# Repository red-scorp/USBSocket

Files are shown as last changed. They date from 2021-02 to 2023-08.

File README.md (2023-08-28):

# USBSocket project

USB Socket board came into existence as alternative to cheap miniUSB adapters which we not good enough for me.
These cheap boards do not care about D+/D- traced being equally long which is essential for USB wiring.
I had to design my own microUSB adapter board to fit my needs.

Following types of boards are available:

- **Type1** is breadboard friendly **microUSB** socket
- **Type2** is cable mount friendly **microUSB** socket
- **Type3** is breadboard friendly **miniUSB** socket
- **Type4** is cable mount friendly **miniUSB** socket
- **Type5** is breadboard friendly **USB** socket
- **Type6** is cable mount friendly **USB** socket
- **Type7** is breadboard friendly **PCB-USB** socket
- **Type8** is cable mount friendly **PCB-USB** socket
- **Type9** is breadboard friendly **USB Type-C** socket
- **Type10** is cable mount friendly **USB Type-C** socket

## USBSocket_Type1_v1.0

**USBSocket_Type1_v1.0** is a simple microUSB adapter board, which mostly designed to be breadboard friendly.

Preview:

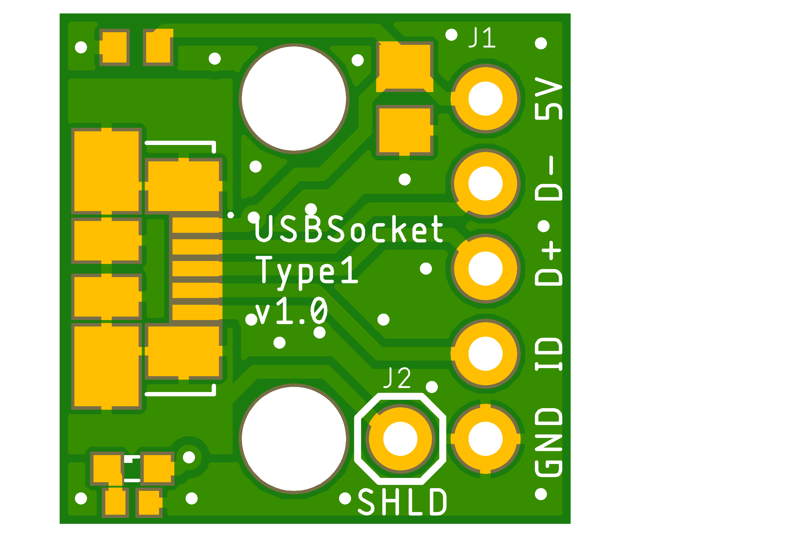
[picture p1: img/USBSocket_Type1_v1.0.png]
USBSocket_Type1_v1.0 preview


[Schematics in PDF format](doc/USBSocket_Type1_v1.0.pdf)

Features:

- 2.54mm (0.1") raster breadboard friendly
- small size
- includes decoupling capacitor
- includes power LED indicator
- 3mm mount holes

CAM files are available.

## USBSocket_Type2_v1.0

**USBSocket_Type2_v1.0** is a simple microUSB adapter board mostly usable for smaller or cable applications.

Preview:

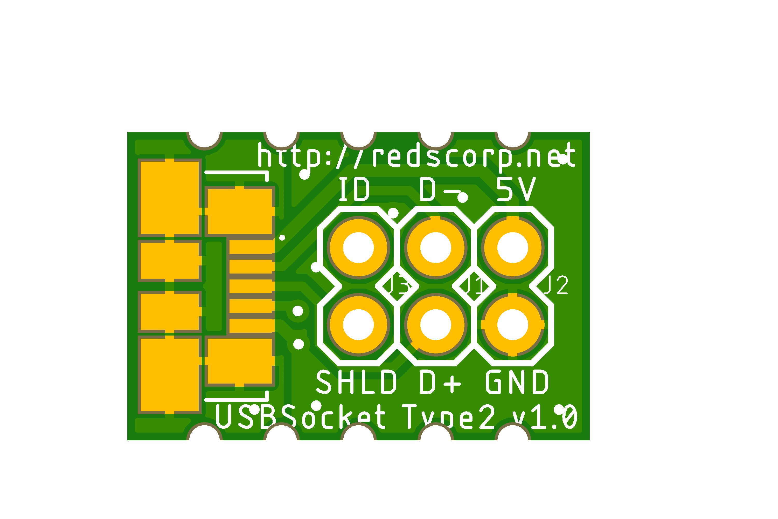
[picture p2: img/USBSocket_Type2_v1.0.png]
USBSocket_Type2_v1.0 preview


[Schematics in PDF format](doc/USBSocket_Type2_v1.0.pdf)

Features:

- 2.54mm (0.1") raster board friendly
- even smaller size
- suitable for cable mount
- shrink-tube friendly

CAM files are available.

## USBSocket_Type3_v1.0

**USBSocket_Type3_v1.0** is a simple miniUSB adapter board, which mostly designed to be breadboard friendly.

Preview:

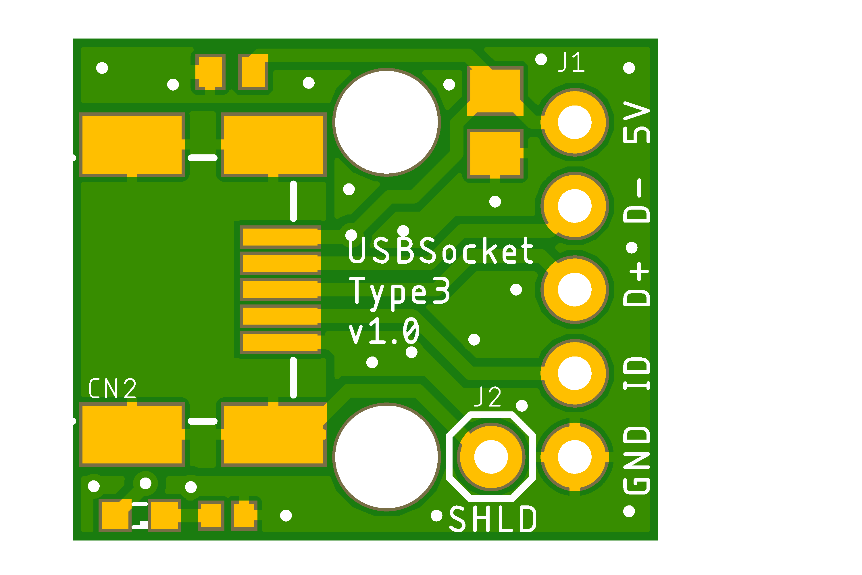
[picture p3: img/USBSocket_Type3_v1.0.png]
USBSocket_Type3_v1.0 preview


[Schematics in PDF format](doc/USBSocket_Type3_v1.0.pdf)

Features:

- 2.54mm (0.1") raster breadboard friendly
- small size
- includes decoupling capacitor
- includes power LED indicator
- 3mm mount holes

CAM files are available.

## USBSocket_Type4_v1.0

**USBSocket_Type4_v1.0** is a simple miniUSB adapter board mostly usable for smaller or cable applications.

Preview:

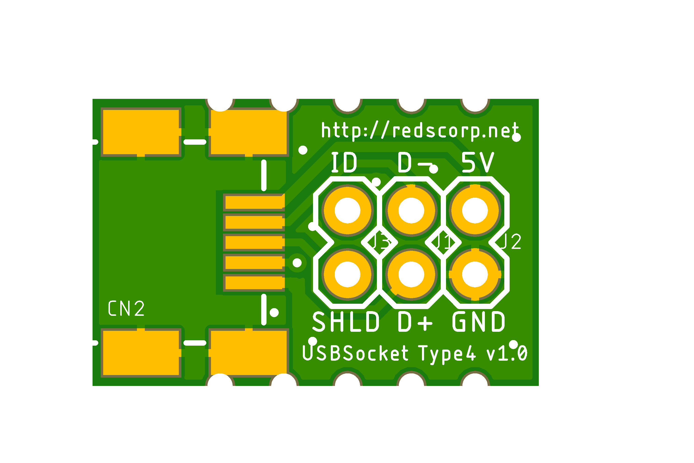
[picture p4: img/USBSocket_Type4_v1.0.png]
USBSocket_Type4_v1.0 preview


[Schematics in PDF format](doc/USBSocket_Type4_v1.0.pdf)

Features:

- 2.54mm (0.1") raster board friendly
- even smaller size
- suitable for cable mount
- shrink-tube friendly

CAM files are available.

## USBSocket_Type5_v1.0

**USBSocket_Type5_v1.0** is a simple USB adapter board, which mostly designed to be breadboard friendly.

Preview:

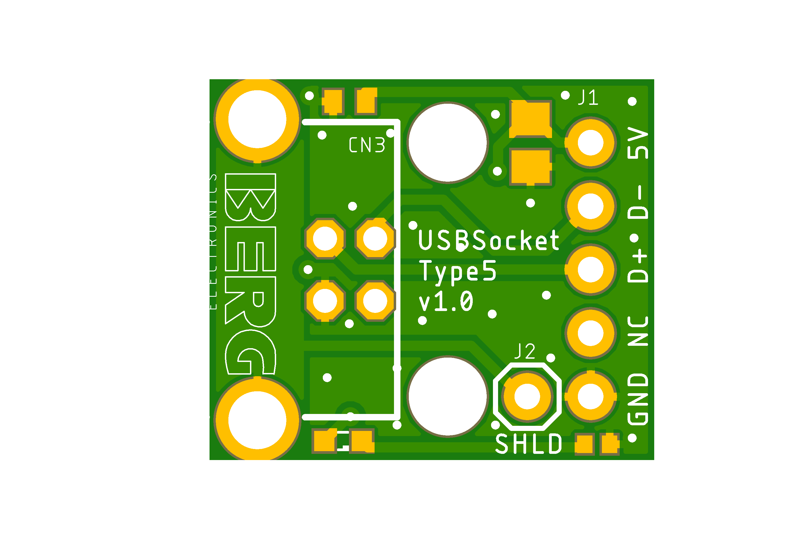
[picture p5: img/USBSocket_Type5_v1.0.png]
USBSocket_Type5_v1.0 preview


[Schematics in PDF format](doc/USBSocket_Type5_v1.0.pdf)

Features:

- 2.54mm (0.1") raster breadboard friendly
- small size
- includes decoupling capacitor
- includes power LED indicator
- 3mm mount holes

CAM files are available.

## USBSocket_Type6_v1.0

**USBSocket_Type6_v1.0** is a simple USB adapter board mostly usable for smaller or cable applications.

Preview:

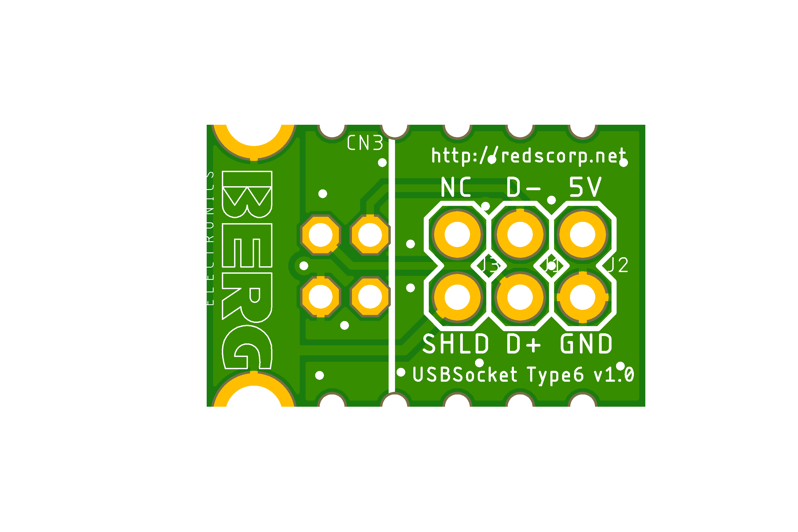
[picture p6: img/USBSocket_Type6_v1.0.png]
USBSocket_Type6_v1.0 preview


[Schematics in PDF format](doc/USBSocket_Type6_v1.0.pdf)

Features:

- 2.54mm (0.1") raster board friendly
- even smaller size
- suitable for cable mount
- shrink-tube friendly

CAM files are available.

## USBSocket_Type7_v1.0

**USBSocket_Type7_v1.0** is a simple PCB-USB adapter board, which mostly designed to be breadboard friendly.
This PCB board should be about 1.6-2.0mm thick!

Preview:

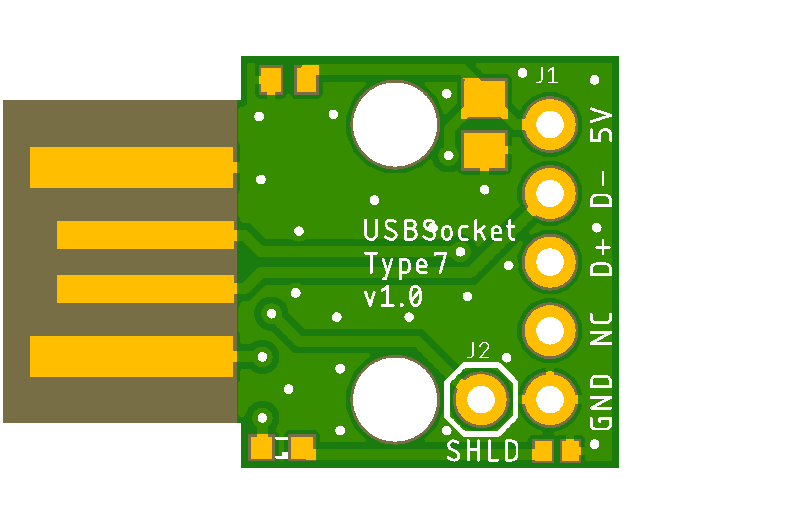
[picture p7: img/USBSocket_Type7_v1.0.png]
USBSocket_Type7_v1.0 preview


[Schematics in PDF format](doc/USBSocket_Type7_v1.0.pdf)

Features:

- 2.54mm (0.1") raster breadboard friendly
- small size
- includes decoupling capacitor
- includes power LED indicator
- 3mm mount holes

CAM files are available.

## USBSocket_Type8_v1.0

**USBSocket_Type8_v1.0** is a simple PCB-USB adapter board mostly usable for smaller or cable applications.
This PCB board should be about 1.6-2.0mm thick!

Preview:

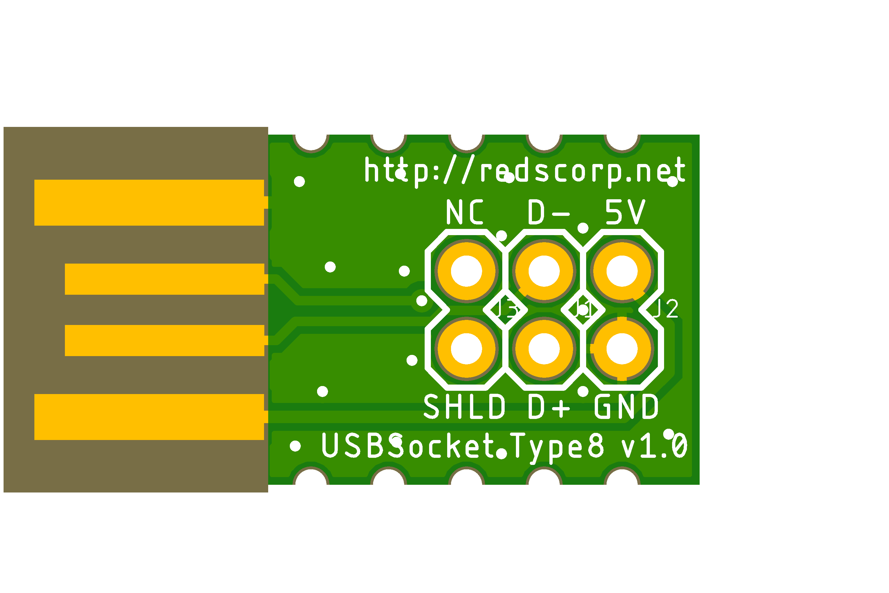
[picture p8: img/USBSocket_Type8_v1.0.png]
USBSocket_Type8_v1.0 preview


[Schematics in PDF format](doc/USBSocket_Type8_v1.0.pdf)

Features:

- 2.54mm (0.1") raster board friendly
- even smaller size
- suitable for cable mount
- shrink-tube friendly

CAM files are available.

## USBSocket_Type9_v1.0

**USBSocket_Type9_v1.0** is a simple USB Type-C adapter board, which mostly designed to be breadboard friendly.

Preview:

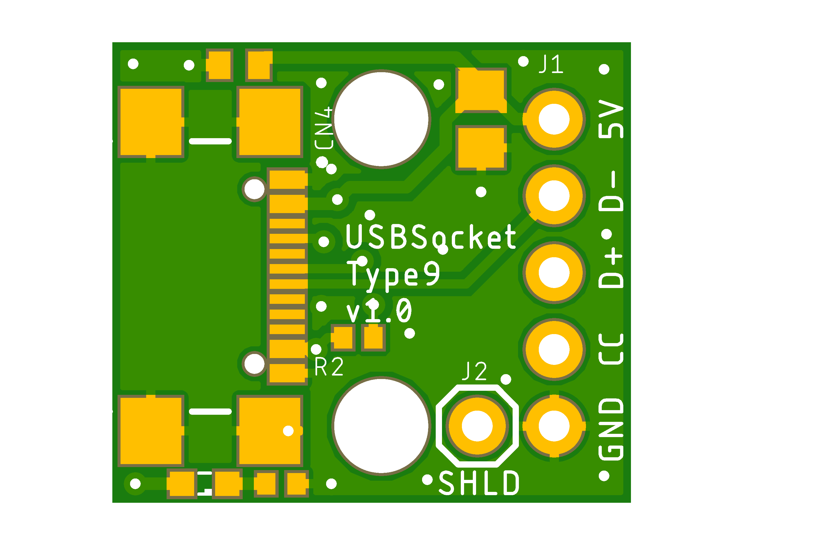
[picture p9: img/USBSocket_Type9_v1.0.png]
USBSocket_Type9_v1.0 preview


[Schematics in PDF format](doc/USBSocket_Type9_v1.0.pdf)

Features:

- 2.54mm (0.1") raster breadboard friendly
- small size
- includes decoupling capacitor
- includes power LED indicator
- 3mm mount holes

CAM files are available.

## USBSocket_Type10_v1.0

**USBSocket_Type10_v1.0** is a simple USB Type-C adapter board mostly usable for smaller or cable applications.

Preview:

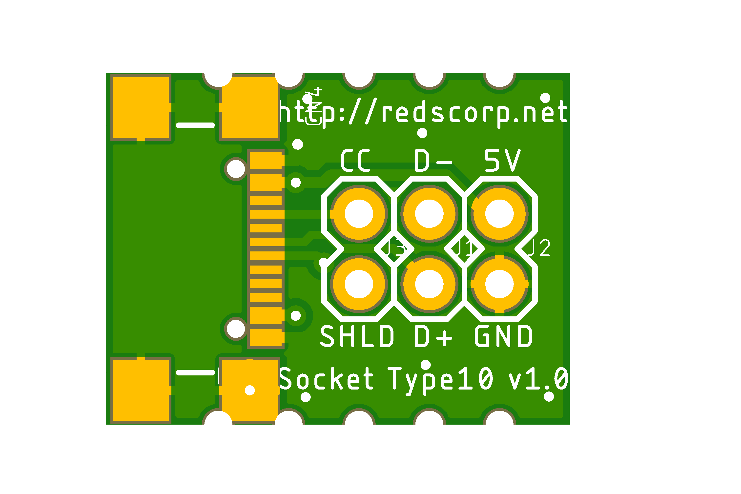
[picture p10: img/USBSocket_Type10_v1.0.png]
USBSocket_Type10_v1.0 preview


[Schematics in PDF format](doc/USBSocket_Type10_v1.0.pdf)

Features:

- 2.54mm (0.1") raster board friendly
- even smaller size
- suitable for cable mount
- shrink-tube friendly

CAM files are available.

## BOM

Bill Of Materials is currently available only for LCSC Electronic Components Distributor, which is probably cheapest anyway.

### LCSC BOM

|Designator  |Part/Value |Package/Footprint |LCSC # |
|---|---|---|---|
|CN1 |MOLEX 473460001 |SMD |C132560  |
|CN2 |MOLEX 675031230 |SMD |C136452  |
|CN3 |MOLEX 670688000 |TH |C114097  |
|CN4 |Hanbo Electronic MC-107S |SMD |C2874570 |
|C1\* |Cap. 47uF |0805 |C109461  |
|C2\* |Cap. 100nF |0402 |C60474 |
|LED1\* |LED Green |0603 |C364559  |
|R1\* |Res. 1K |0402 |C384390  |
|R2\* |Res. 56K |0402 |C25796 |

\*) These passive components are optional but it's recommended to install them.

## How to help

Your contributions as code, resources, or finances are welcome! Please contact me directly via email at andriy.golovnya@gmail.com or through my [GitHub profile](https://github.com/red-scorp).

If you'd like to make a financial contribution, you can donate via [PayPal](http://paypal.me/redscorp) or [Ko-Fi](http://ko-fi.com/redscorp). Your support is greatly appreciated.

Thanks in advance!

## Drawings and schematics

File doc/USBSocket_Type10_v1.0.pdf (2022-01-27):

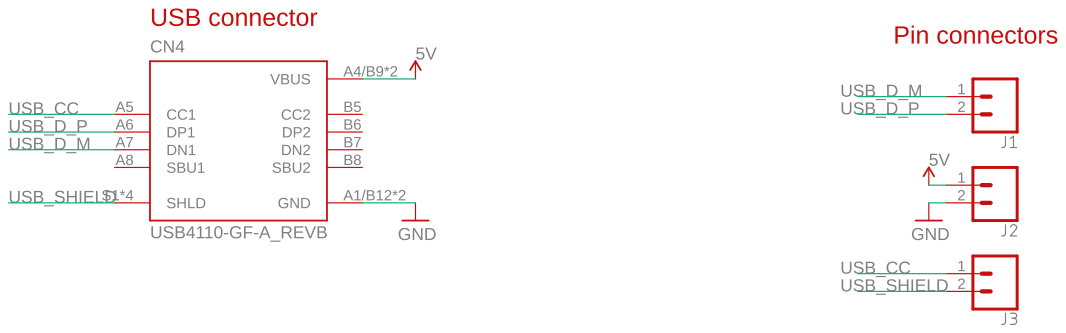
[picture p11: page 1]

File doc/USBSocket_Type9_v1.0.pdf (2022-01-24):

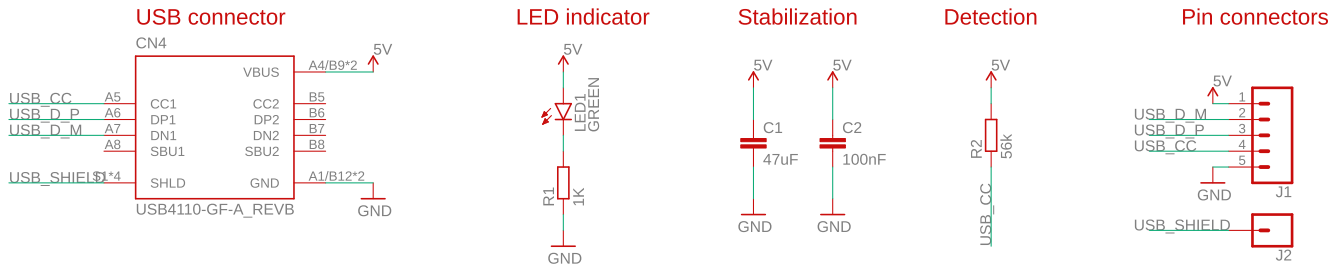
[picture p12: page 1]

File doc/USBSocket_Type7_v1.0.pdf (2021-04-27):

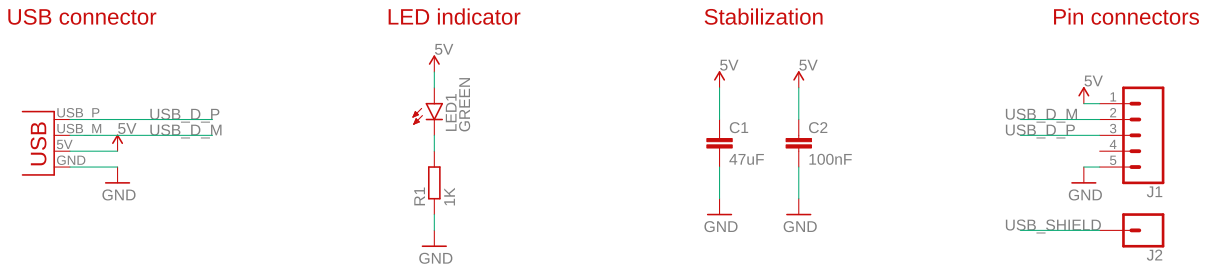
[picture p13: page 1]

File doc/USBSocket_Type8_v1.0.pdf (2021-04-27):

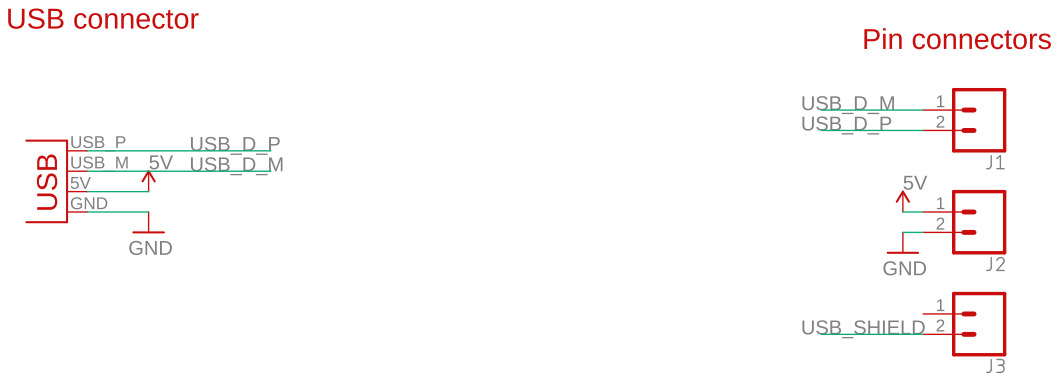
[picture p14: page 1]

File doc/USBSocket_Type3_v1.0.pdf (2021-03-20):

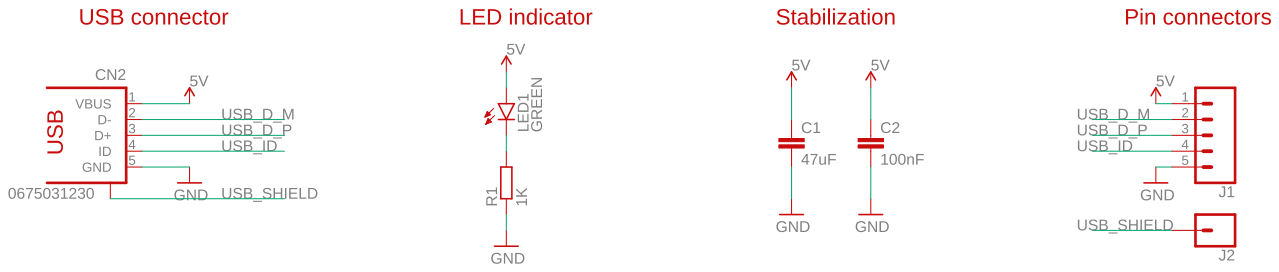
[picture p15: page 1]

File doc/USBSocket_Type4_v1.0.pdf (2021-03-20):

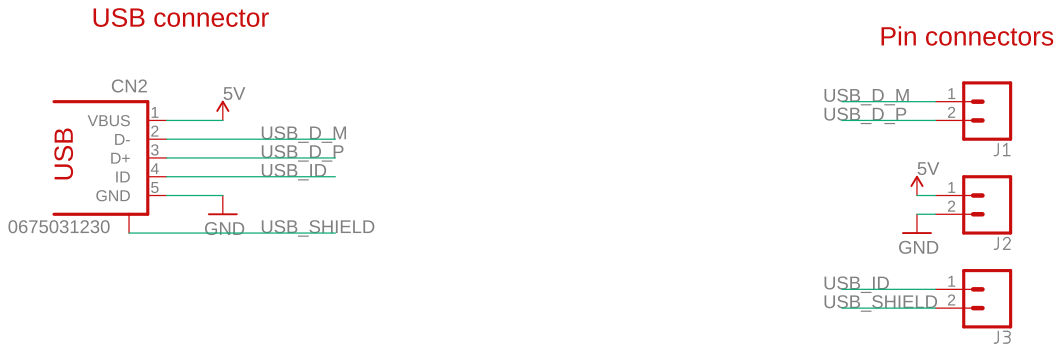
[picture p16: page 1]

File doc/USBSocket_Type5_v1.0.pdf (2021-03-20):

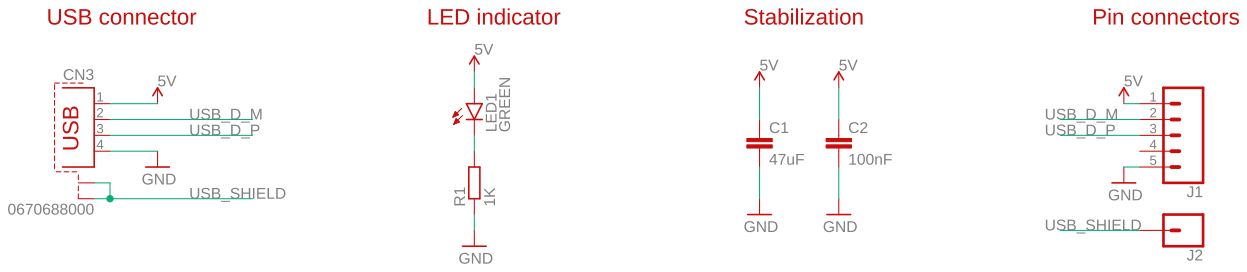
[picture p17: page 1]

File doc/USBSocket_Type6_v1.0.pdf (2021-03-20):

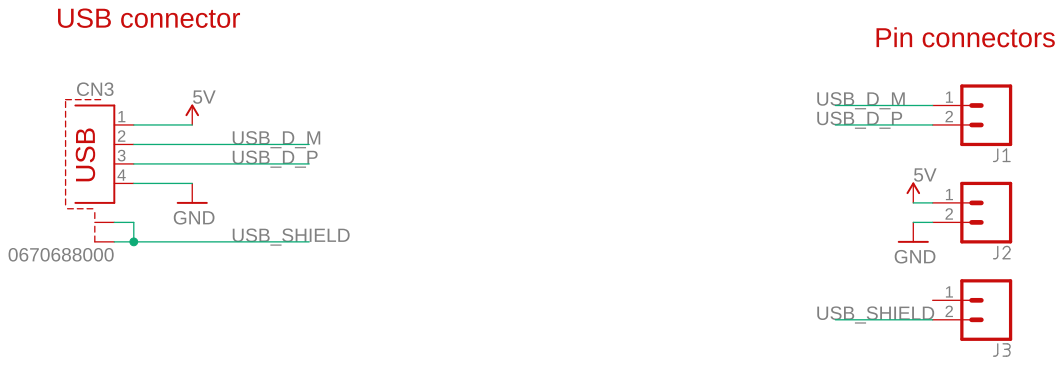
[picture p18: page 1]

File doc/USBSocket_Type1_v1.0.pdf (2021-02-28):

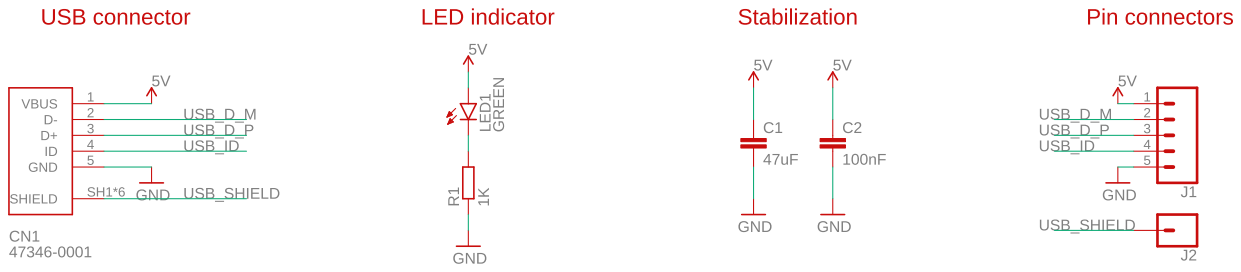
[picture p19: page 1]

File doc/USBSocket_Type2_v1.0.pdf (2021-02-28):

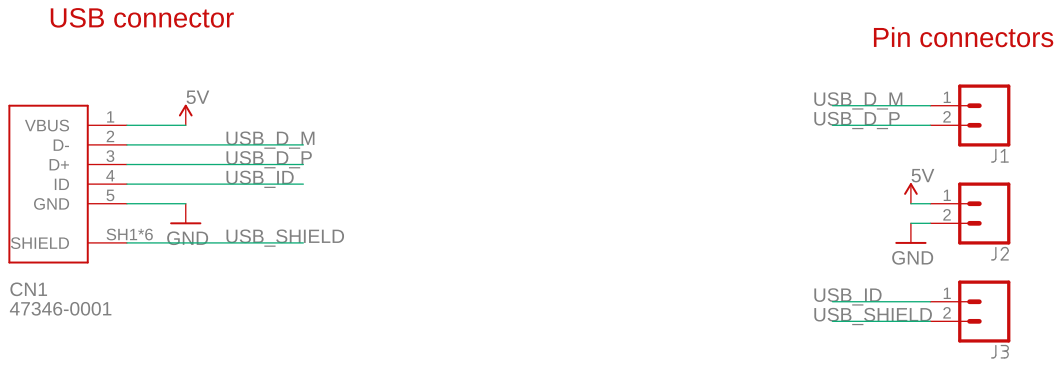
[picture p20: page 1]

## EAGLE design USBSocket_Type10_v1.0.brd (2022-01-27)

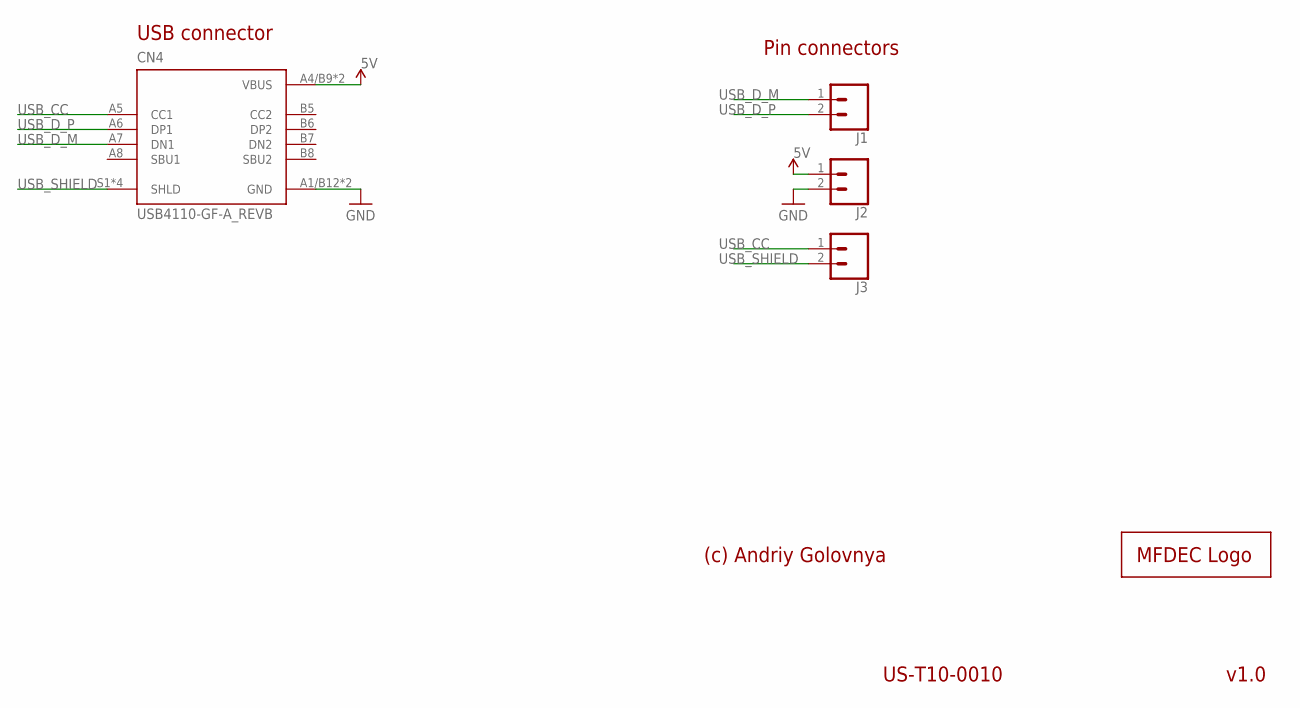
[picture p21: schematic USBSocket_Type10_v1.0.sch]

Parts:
CN4: USB4110-GF-A_REVB; GCT_USB4110-GF-A_REVB
J1, J2, J3: CONN_02; 1X02
LOGO1: MFDECLOGO_L_10MM; MFDEC_L_10MM

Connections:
5V: CN4.A4/B9 (VBUS), CN4.B4/A9 (VBUS), J2.1
GND: CN4.A1/B12 (GND), CN4.B1/A12 (GND), J2.2
USB_CC: CN4.A5 (CC1), J3.1
USB_D_M: CN4.A7 (DN1), J1.1
USB_D_P: CN4.A6 (DP1), J1.2
USB_SHIELD: CN4.S1 (SHLD), CN4.S2 (SHLD), CN4.S3 (SHLD), CN4.S4 (SHLD), J3.2

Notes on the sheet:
USB connector
v1.0
(c) Andriy Golovnya
US-T10-0010
Pin connectors

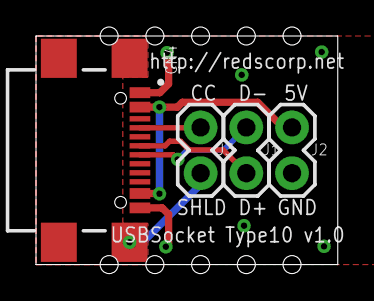
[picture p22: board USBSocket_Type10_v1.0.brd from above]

Board: 2 copper layers, 16.8 x 12.7 mm, 5 parts (1 on the bottom side), 6 nets.

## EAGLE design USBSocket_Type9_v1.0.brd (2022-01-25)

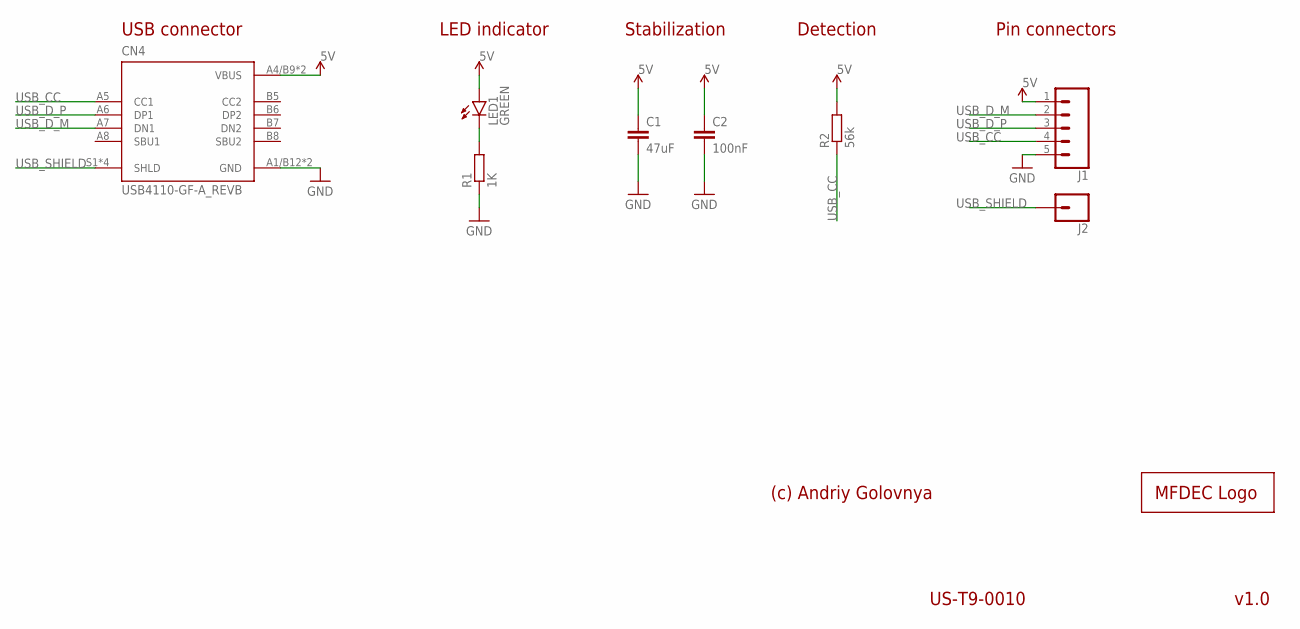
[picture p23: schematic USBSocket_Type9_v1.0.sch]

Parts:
C1: 47uF; C0805
C2: 100nF; C0402
CN4: USB4110-GF-A_REVB; GCT_USB4110-GF-A_REVB
J1: CONN_05PTH; 1X05
J2: CONN_01; 1X01
LED1: GREEN; SML0603
LOGO1: MFDECLOGO_L_10MM; MFDEC_L_10MM
R1: 1K; R0402
R2: 56k; R0402

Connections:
5V: C1.1, C2.1, CN4.A4/B9 (VBUS), CN4.B4/A9 (VBUS), J1.1, LED1.A, R2.2
GND: C1.2, C2.2, CN4.A1/B12 (GND), CN4.B1/A12 (GND), J1.5, R1.1
unnamed: LED1.C, R1.2
USB_CC: CN4.A5 (CC1), J1.4, R2.1
USB_D_M: CN4.A7 (DN1), J1.2
USB_D_P: CN4.A6 (DP1), J1.3
USB_SHIELD: CN4.S1 (SHLD), CN4.S2 (SHLD), CN4.S3 (SHLD), CN4.S4 (SHLD), J2.1

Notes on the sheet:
USB connector
v1.0
LED indicator
(c) Andriy Golovnya
US-T9-0010
Stabilization
Pin connectors
Detection

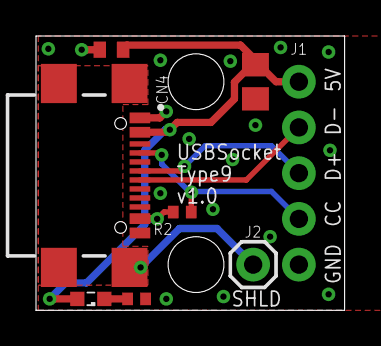
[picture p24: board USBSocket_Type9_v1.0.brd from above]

Board: 2 copper layers, 17.1 x 15.2 mm, 9 parts (1 on the bottom side), 7 nets.

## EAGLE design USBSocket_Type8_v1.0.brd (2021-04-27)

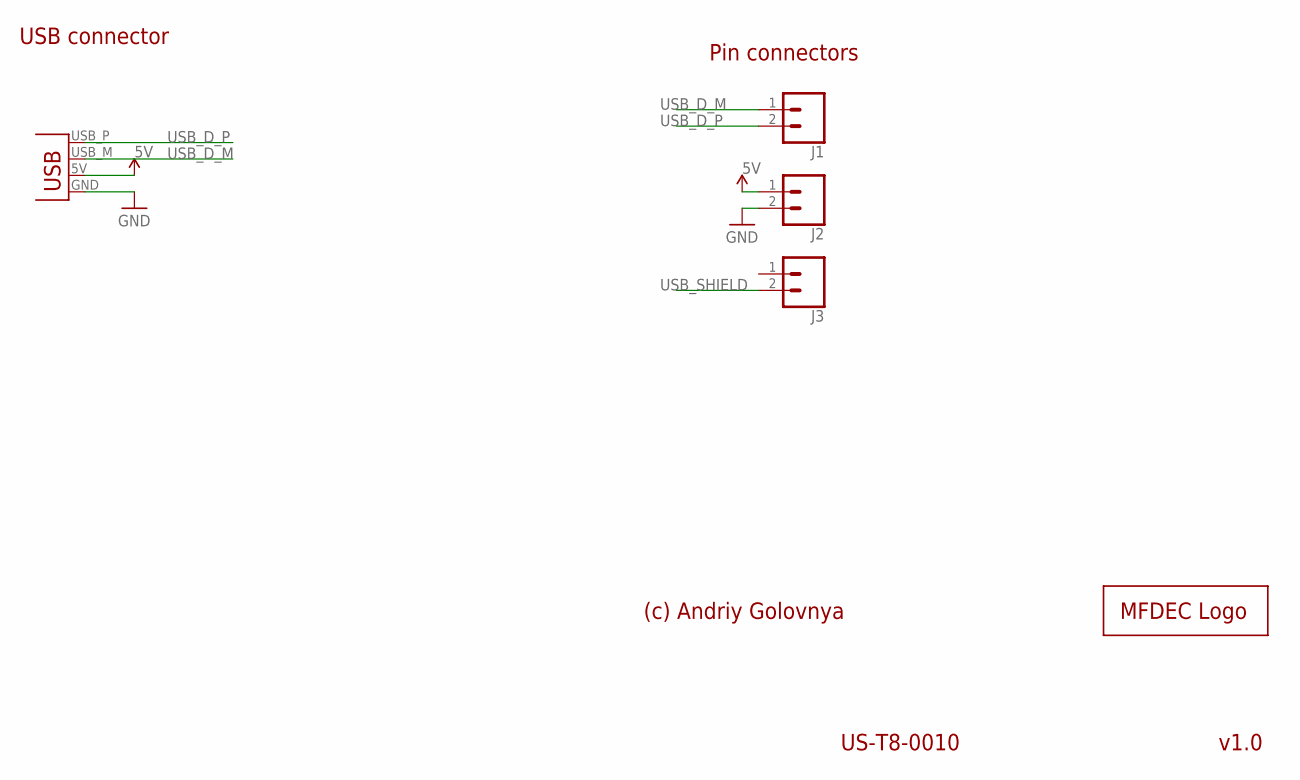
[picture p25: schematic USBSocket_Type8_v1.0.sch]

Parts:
J1, J2, J3: CONN_02; 1X02
LOGO1: MFDECLOGO_L_10MM; MFDEC_L_10MM
X1: USBPCB; USB-A-PCB

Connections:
5V: J2.1, X1.5V (VBUS)
GND: J2.2, X1.GND
USB_D_M: J1.1, X1.USB_M (D-)
USB_D_P: J1.2, X1.USB_P (D+)
USB_SHIELD: J3.2

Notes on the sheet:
USB connector
v1.0
(c) Andriy Golovnya
US-T8-0010
Pin connectors

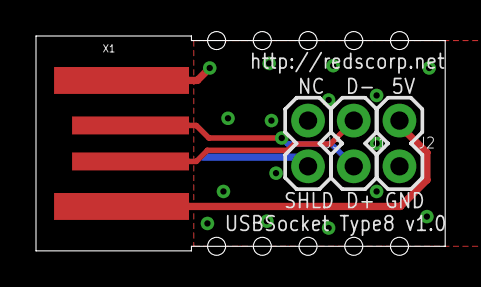
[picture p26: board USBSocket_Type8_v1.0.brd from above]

Board: 2 copper layers, 22.7 x 11.9 mm, 5 parts (1 on the bottom side), 4 nets.

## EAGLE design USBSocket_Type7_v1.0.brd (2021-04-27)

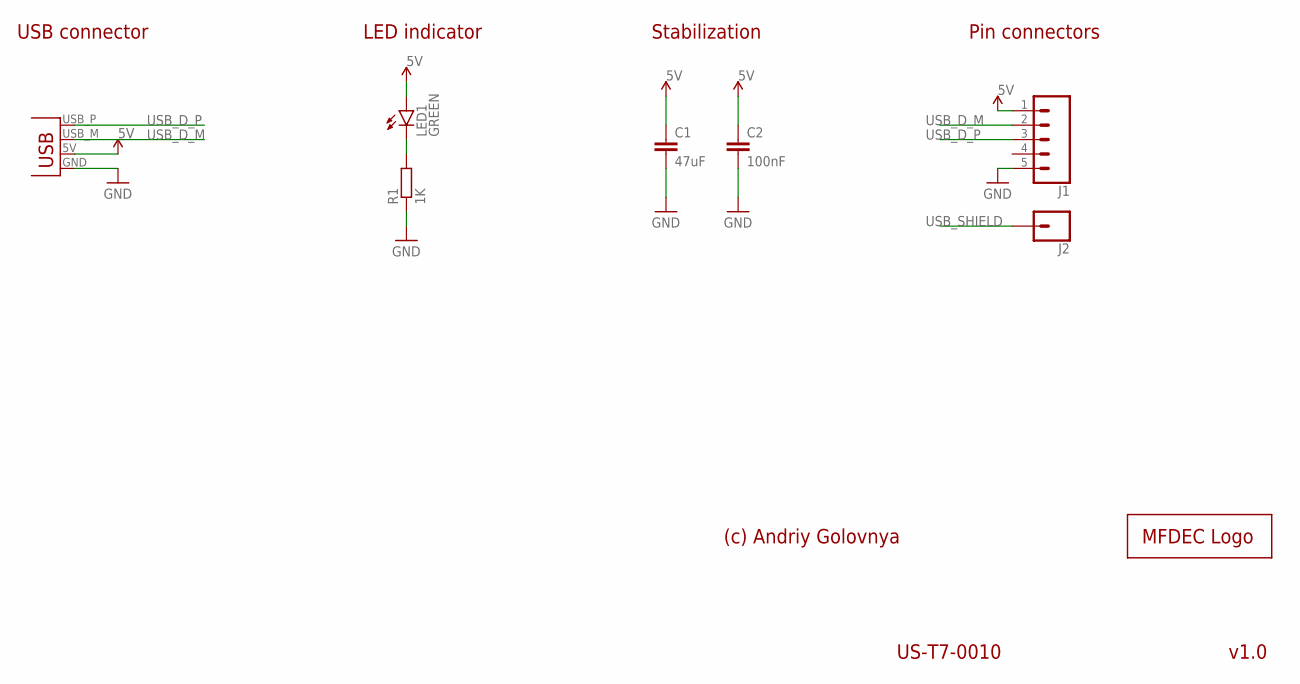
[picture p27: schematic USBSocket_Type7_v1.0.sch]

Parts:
C1: 47uF; C0805
C2: 100nF; C0402
J1: CONN_05PTH; 1X05
J2: CONN_01; 1X01
LED1: GREEN; SML0603
LOGO1: MFDECLOGO_L_10MM; MFDEC_L_10MM
R1: 1K; R0402
X1: USBPCB; USB-A-PCB

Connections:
5V: C1.1, C2.1, J1.1, LED1.A, X1.5V (VBUS)
GND: C1.2, C2.2, J1.5, R1.1, X1.GND
unnamed: LED1.C, R1.2
USB_D_M: J1.2, X1.USB_M (D-)
USB_D_P: J1.3, X1.USB_P (D+)
USB_SHIELD: J2.1

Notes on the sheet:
USB connector
v1.0
LED indicator
(c) Andriy Golovnya
US-T7-0010
Stabilization
Pin connectors

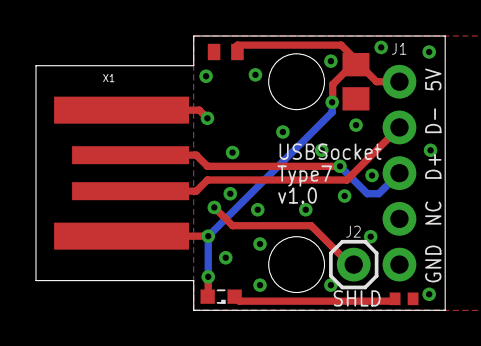
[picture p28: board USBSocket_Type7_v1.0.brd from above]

Board: 2 copper layers, 22.7 x 15.2 mm, 8 parts (1 on the bottom side), 5 nets.

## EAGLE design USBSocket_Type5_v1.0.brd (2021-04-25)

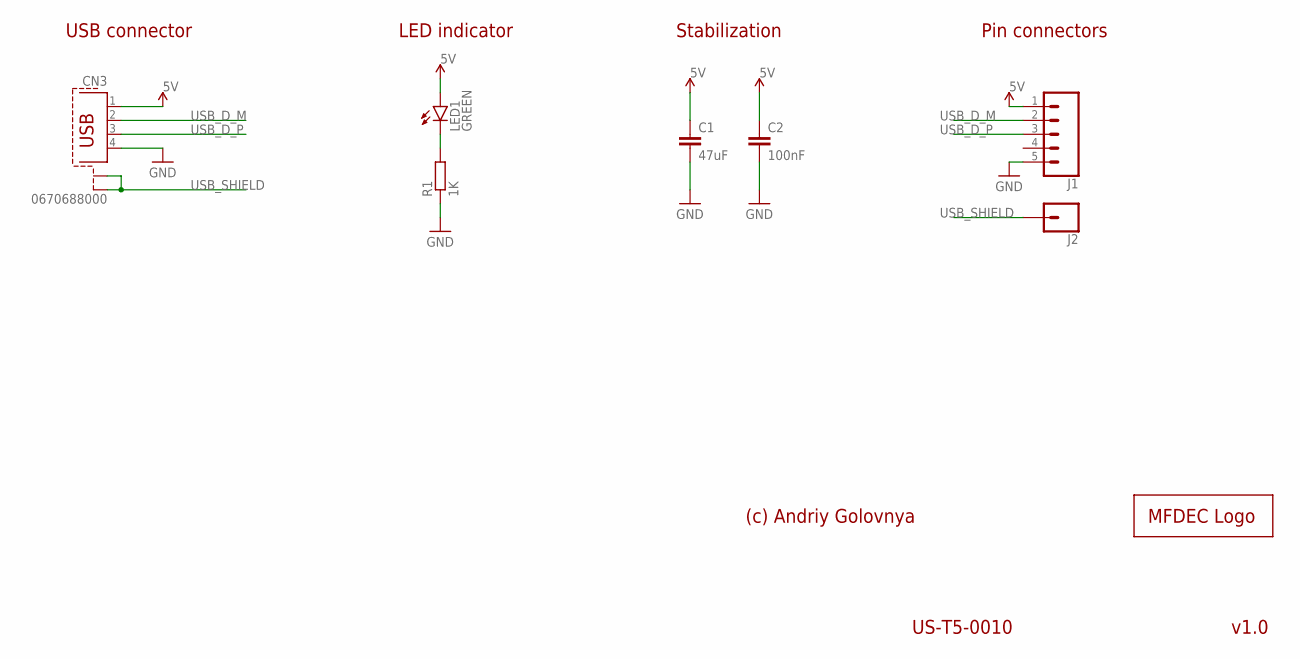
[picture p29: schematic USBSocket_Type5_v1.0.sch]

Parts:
C1: 47uF; C0805
C2: 100nF; C0402
CN3: 0670688000; PN61729-S
J1: CONN_05PTH; 1X05
J2: CONN_01; 1X01
LED1: GREEN; SML0603
LOGO1: MFDECLOGO_L_10MM; MFDEC_L_10MM
R1: 1K; R0402

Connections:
5V: C1.1, C2.1, CN3.1, J1.1, LED1.A
GND: C1.2, C2.2, CN3.4, J1.5, R1.1
unnamed: LED1.C, R1.2
USB_D_M: CN3.2, J1.2
USB_D_P: CN3.3, J1.3
USB_SHIELD: CN3.S1, CN3.S2, J2.1

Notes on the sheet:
USB connector
v1.0
LED indicator
(c) Andriy Golovnya
US-T5-0010
Stabilization
Pin connectors

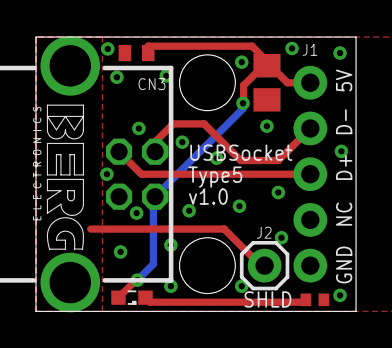
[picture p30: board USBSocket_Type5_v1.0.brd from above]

Board: 2 copper layers, 17.8 x 15.2 mm, 8 parts (1 on the bottom side), 6 nets.

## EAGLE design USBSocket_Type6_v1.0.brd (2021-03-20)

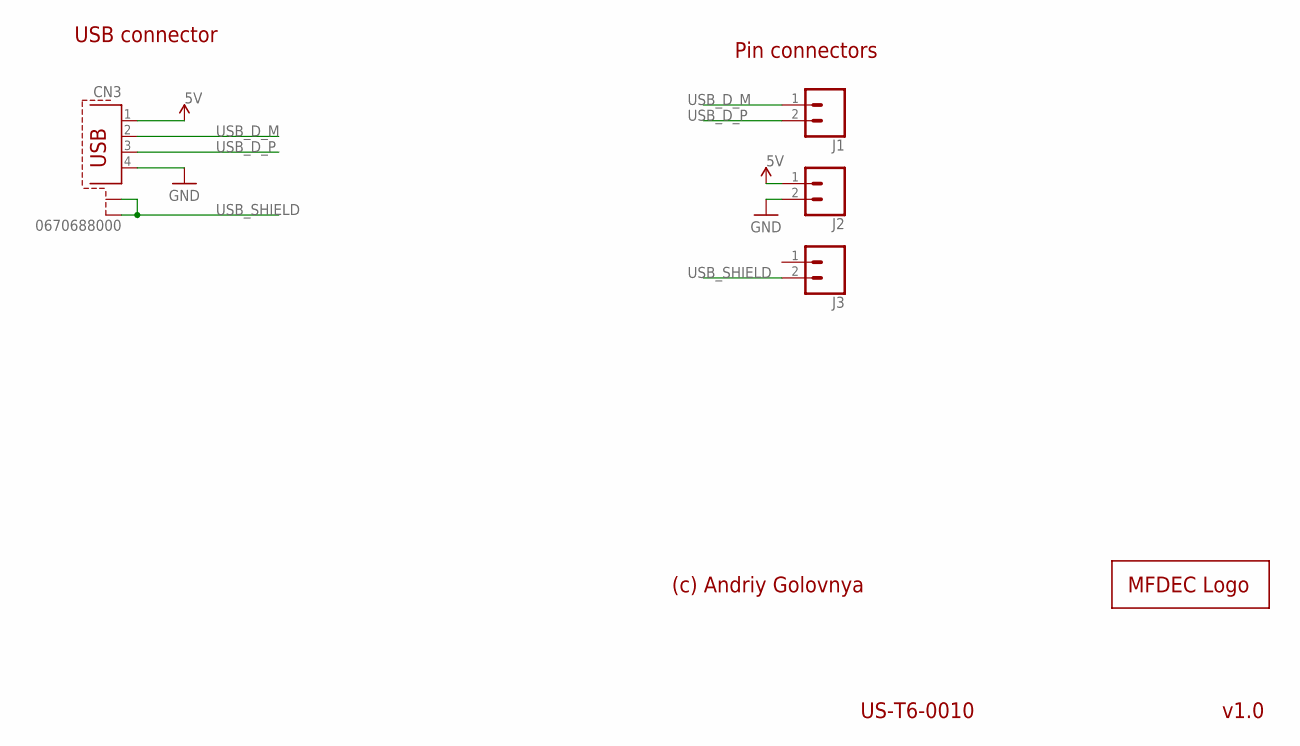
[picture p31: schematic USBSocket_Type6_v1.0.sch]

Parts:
CN3: 0670688000; PN61729-S
J1, J2, J3: CONN_02; 1X02
LOGO1: MFDECLOGO_L_10MM; MFDEC_L_10MM

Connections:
5V: CN3.1, J2.1
GND: CN3.4, J2.2
USB_D_M: CN3.2, J1.1
USB_D_P: CN3.3, J1.2
USB_SHIELD: CN3.S1, CN3.S2, J3.2

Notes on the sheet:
USB connector
v1.0
(c) Andriy Golovnya
US-T6-0010
Pin connectors

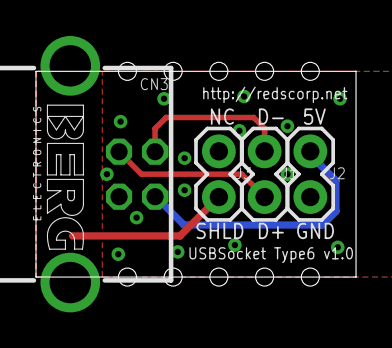
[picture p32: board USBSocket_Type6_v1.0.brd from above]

Board: 2 copper layers, 17.8 x 11.4 mm, 5 parts (1 on the bottom side), 5 nets.

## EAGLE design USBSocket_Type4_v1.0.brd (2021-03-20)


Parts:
CN2: 0675031230; PMX42_56579-0576
J1, J2, J3: CONN_02; 1X02
LOGO1: MFDECLOGO_L_10MM; MFDEC_L_10MM

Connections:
5V: CN2.1 (VBUS), J2.1
GND: CN2.5 (GND), J2.2
USB_D_M: CN2.2 (D-), J1.1
USB_D_P: CN2.3 (D+), J1.2
USB_ID: CN2.4 (ID), J3.1
USB_SHIELD: CN2.S1 (S), CN2.S2 (S), CN2.S3 (S), CN2.S4 (S), J3.2

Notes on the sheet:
USB connector
v1.0
(c) Andriy Golovnya
US-T4-0010
Pin connectors


Board: 2 copper layers, 17.8 x 11.4 mm, 5 parts (1 on the bottom side), 6 nets.

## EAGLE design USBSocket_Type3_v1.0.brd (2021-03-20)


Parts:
C1: 47uF; C0805
C2: 100nF; C0402
CN2: 0675031230; PMX42_56579-0576
J1: CONN_05PTH; 1X05
J2: CONN_01; 1X01
LED1: GREEN; SML0603
LOGO1: MFDECLOGO_L_10MM; MFDEC_L_10MM
R1: 1K; R0402

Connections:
5V: C1.1, C2.1, CN2.1 (VBUS), J1.1, LED1.A
GND: C1.2, C2.2, CN2.5 (GND), J1.5, R1.1
unnamed: LED1.C, R1.2
USB_D_M: CN2.2 (D-), J1.2
USB_D_P: CN2.3 (D+), J1.3
USB_ID: CN2.4 (ID), J1.4
USB_SHIELD: CN2.S1 (S), CN2.S2 (S), CN2.S3 (S), CN2.S4 (S), J2.1

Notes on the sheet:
USB connector
v1.0
LED indicator
(c) Andriy Golovnya
US-T3-0010
Stabilization
Pin connectors


Board: 2 copper layers, 17.8 x 15.2 mm, 8 parts (1 on the bottom side), 7 nets.

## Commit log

2021-02-28 Added Type1 USB socket board.
    [USBSocket_Type1_v1.0.brd, USBSocket_Type1_v1.0.sch]
2021-02-28 Added Type2 board.
    [USBSocket_Type2_v1.0.brd, USBSocket_Type2_v1.0.sch]
2021-02-28 Generated CAM for Type1 and Type2 boards. Generated PNG preview images. Generated PDF schematics.
2021-03-19 Approved ERC warnings.
    [USBSocket_Type1_v1.0.sch, USBSocket_Type2_v1.0.sch]
2021-03-20 Added Type3-6 boards
    [USBSocket_Type3_v1.0.brd, USBSocket_Type3_v1.0.sch, USBSocket_Type4_v1.0.brd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]
2021-03-20 Added PDF schematics
2021-04-25 Fixed bottom silkscreen text.
    [USBSocket_Type5_v1.0.brd]
2021-04-25 Added type7 board
    [USBSocket_Type7_v1.0.brd, USBSocket_Type7_v1.0.sch]
2021-04-27 Fixed schematic and routing for t7 board.
    [USBSocket_Type7_v1.0.brd, USBSocket_Type7_v1.0.sch]
2021-04-27 Added type8 board.
    [USBSocket_Type8_v1.0.brd, USBSocket_Type8_v1.0.sch]
2021-04-27 Add PDF schematics and PNG preview for t7 and t8.
2021-04-27 Added CAM files for t7 and t8 boards.
2021-04-27 minor fixes.
    [USBSocket_Type8_v1.0.brd]
2021-12-03 Fixed information about thickness of boards for type 7 and 8.
2022-01-24 Added type9 board.
    [USBSocket_Type9_v1.0.brd, USBSocket_Type9_v1.0.sch]
2022-01-24 Generated PDF schematics. Generated PNG preview.
2022-01-25 Moved few stuff around on type 9 board. Generated CAM files. Generated PNG preview.
    [USBSocket_Type9_v1.0.brd]
2022-01-25 Made type 9 board a bit shorter. Generated CAM files. Generated PNG preview.
    [USBSocket_Type9_v1.0.brd]
2022-01-27 Added type10 board.
    [USBSocket_Type10_v1.0.brd, USBSocket_Type10_v1.0.sch]

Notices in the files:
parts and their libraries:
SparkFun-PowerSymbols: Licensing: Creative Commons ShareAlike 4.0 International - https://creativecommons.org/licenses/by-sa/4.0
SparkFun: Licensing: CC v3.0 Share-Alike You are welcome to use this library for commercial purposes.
